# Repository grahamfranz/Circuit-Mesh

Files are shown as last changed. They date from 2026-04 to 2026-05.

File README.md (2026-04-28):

# circuit mesh

A parametric 3D-printable prototyping board for poke-through component mounting. Push component leads through the holes, twist or solder connections underneath — same workflow as the classic paper-over-cardboard method, but reusable and dimensionally consistent.

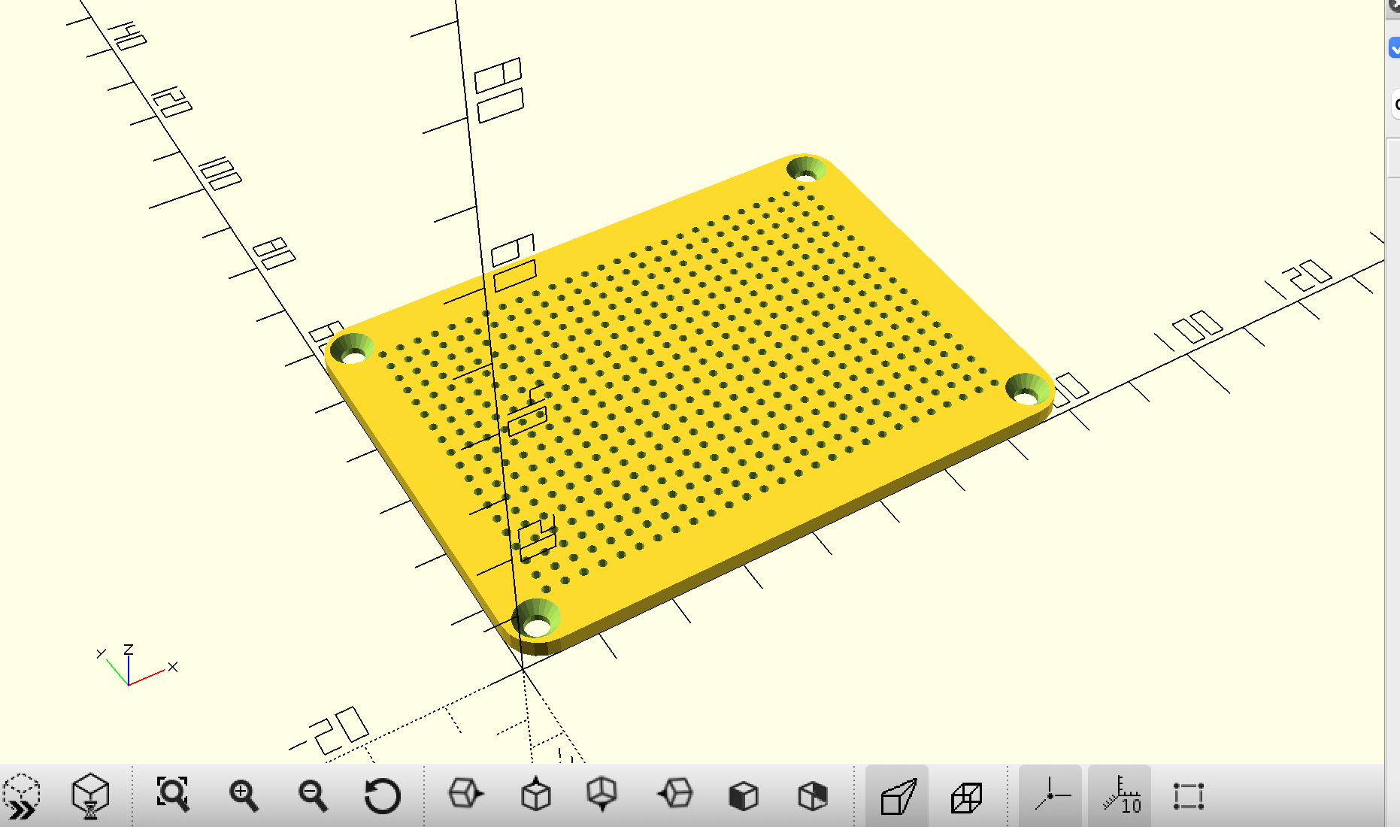
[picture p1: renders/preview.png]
circuit mesh render


---

## Hammond die-cast enclosure presets

Set the `preset` parameter to size the board footprint automatically for a standard Hammond die-cast enclosure. The board will fit inside the enclosure, accounting for wall thickness. The dimensions below are the *outer* enclosure footprints; `enclosure_wall_thick` (default 2.5mm per side) is automatically subtracted so your board fits with clearance.

| Preset | L (mm) | W (mm) | H (mm) | Notes |
|---|---|---|---|---|
| `1590A` |  92.5  |  38.5  |  31 | Micro, single-knob builds |
| `1590B` | 112 |  60 |  31 | Standard "Boss-style" pedal  |
| `1590BB`  | 119 |  94 |  34 | 3–4 knob builds |
| `125B` | 121 |  66 |  39 | Deeper 1590B alternative |
| `custom`  | — |  — |  — | Use `custom_board_width` / `custom_board_depth` |

`board_thick` (PCB thickness, default 2.5 mm) and `enclosure_wall_thick` (default 2.5 mm per side) are independent of the preset and should be adjusted separately based on your enclosure and material.

---

## print settings

- **Material:** TPU recommended for best grip. PETG works. PLA is functional but stiff.
- **Layer height:** 0.15–0.2mm
- **Infill:** 100% (it's thin — just do it)
- **Supports:** None needed
- **Orientation:** Flat on the bed, holes vertical
- **Nozzle/speed:** Small holes benefit from a 0.4mm nozzle and slow perimeter speed (20–25mm/s). Larger nozzles or fast speeds may produce irregular holes.

---

## parameters

Open `circuit_mesh.scad` in [OpenSCAD](https://openscad.org) and adjust the values at the top:

| Parameter | Default | Description |
|---|---|---|
| `preset` | `"custom"` | Hammond enclosure preset — see table above |
| `custom_board_width` | 80mm | Board width, used only when `preset = "custom"` |
| `custom_board_depth` | 60mm | Board depth, used only when `preset = "custom"` |
| `enclosure_wall_thick` | 2.5mm | Wall thickness of Hammond enclosure per side — subtracted automatically from preset dimensions |
| `board_thick` | 2.5mm | Thickness — more grip, harder insertion. Can be reduced to 2.0mm for lighter builds; consider 3mm if using screw holes |
| `hole_dia` | 1.2mm | Lead hole diameter — tune per material |
| `pitch` | 2.54mm | Hole spacing (standard component pitch) |
| `margin` | 5mm | Border around the hole grid |
| `corner_radius` | 5mm | Radius of rounded corners to fit Hammond enclosure corners |
| `add_screw_holes` | true | Corner M3 mounting holes with countersink — set to false to disable |
| `screw_margin` | 4mm | Distance from board corner to screw center |
| `countersink_dia` | 6.0mm | M3 flat head countersink diameter |
| `countersink_depth` | 1.5mm | Depth of countersink recess |

Hit **F6** to render, then **File → Export → STL**.

### hole diameter tuning

FDM printers tend to print holes slightly larger than specified. Hole size significantly affects insertion feel and component grip. The default (1.2mm) works well across materials. Suggested adjustments:

- TPU: 0.85mm (tighter tolerance for better grip)
- PETG: 1.2–2.0mm (larger holes allow easy component insertion; leads bend naturally)
- PLA: 1.0–1.2mm (smaller than PETG but still loose enough for easy insertion without forcing)

Resin printers may require tighter tolerances (closer to 0.85mm) due to higher accuracy.

---

## pre-rendered stls

Ready-to-print STL files for all Hammond enclosure presets are in the `renders/` folder:

| Filename | Preset | Grid | File size |
|---|---|---|---|
| `circuit_mesh_1590A.stl` | 1590A | 30 × 9 (270 holes) | 2.2M |
| `circuit_mesh_1590B.stl` | 1590B | 38 × 17 (646 holes) | 5.1M |
| `circuit_mesh_1590BB.stl` | 1590BB | 40 × 31 (1,240 holes) | 9.6M |
| `circuit_mesh_125B.stl` | 125B | 41 × 20 (820 holes) | 6.4M |
| `circuit_mesh_custom.stl` | custom | 27 × 19 (513 holes) | 4.1M |

Just download and print — no OpenSCAD needed. To customize, edit `circuit_mesh.scad`, render with **F6**, and export to STL via **File → Export**.

---

## use

- Push component leads through from the top
- Twist leads together underneath to connect, or solder for permanent joints
- Standard 2.54mm pitch means DIP ICs, resistors, capacitors, TO-92 transistors all fit naturally

---

## license

MIT

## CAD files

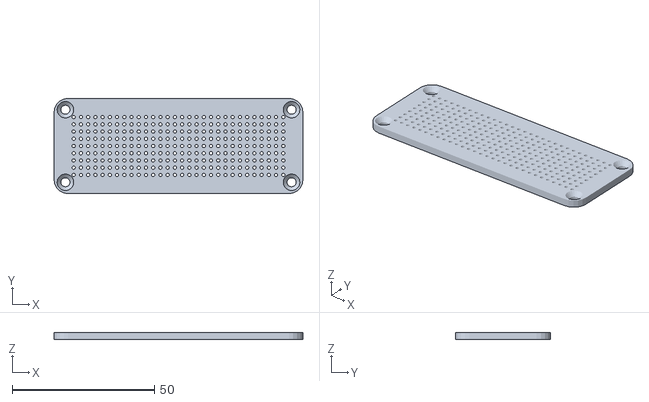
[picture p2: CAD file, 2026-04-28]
renders/circuit_mesh_1590A.stl
87.5 x 33.5 x 2.50

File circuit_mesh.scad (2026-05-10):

// ============================================
// Poke-Through Prototyping Board
// ============================================

// --- Hammond die-cast enclosure preset ---
// Options: "1590A"  (92.5 x 38.5 mm outer, 31 mm deep)
//          "1590B"  (112  x 60   mm outer, 31 mm deep)
//          "1590BB" (119  x 94   mm outer, 34 mm deep)
//          "125B"   (121  x 66   mm outer, 39 mm deep)
//          "barre_controller" – Barre-Controller enclosure mode (4 barres, default 37 mm pitch)
//                               Board: 106 x 133 mm. Keep screw_margin = 4 (default).
//                               Place board at (12, 12) mm from the lower-panel outer corner
//                               so the four M3 screws land on the corner standoffs.
//                               ~8 mm component clearance above the board inside the shell.
//          "custom" - enter your own dimensions in custom_board_width / custom_board_depth
preset = "custom"; // [1590A, 1590B, 1590BB, 125B, barre_controller, custom]

// Wall thickness of Hammond enclosure - subtract from outer dimensions to get inner space
// Typical die-cast boxes: 2.5mm per side = 5mm total reduction
enclosure_wall_thick = 2.5;  // mm - adjust if your enclosure has different wall thickness

// Board footprint - edit these only when preset = "custom":
custom_board_width = 80;  // mm
custom_board_depth = 60;  // mm

// Outer dimensions of Hammond boxes (from specifications)
outer_board_width = preset == "1590A"           ?  92.5 :
                    preset == "1590B"           ? 112   :
                    preset == "1590BB"          ? 119   :
                    preset == "125B"            ? 121   :
                    preset == "barre_controller"? 106   :
                    custom_board_width;

outer_board_depth = preset == "1590A"           ?  38.5 :
                    preset == "1590B"           ?  60   :
                    preset == "1590BB"          ?  94   :
                    preset == "125B"            ?  66   :
                    preset == "barre_controller"? 133   :
                    custom_board_depth;

// Subtract wall thickness on both sides (2x wall_thick) to get dimensions that fit inside.
// barre_controller uses direct board dimensions (no wall subtraction needed).
is_custom = (preset == "custom") || (preset == "barre_controller");
board_width = is_custom ? outer_board_width : (outer_board_width - 2*enclosure_wall_thick);
board_depth = is_custom ? outer_board_depth : (outer_board_depth - 2*enclosure_wall_thick);

// Enclosure interior height - informational reference, not used in board geometry.
// Tells you how much vertical clearance the chosen Hammond box provides.
enclosure_height = preset == "1590A"           ? 31 :
                   preset == "1590B"           ? 31 :
                   preset == "1590BB"          ? 34 :
                   preset == "125B"            ? 39 :
                   preset == "barre_controller"?  8 :  // mm above board inside shell
                   0;   // 0 = no preset selected

board_thick  = 2.5;   // mm - thicker = more grip, harder to insert (2.0mm for lighter builds)

hole_dia     = 1.2;   // mm - tuning per material and printer:
                      // TPU: 0.85mm | PETG: 1.2-2.0mm | PLA: 1.0-1.2mm
                      // Larger holes prevent tight insertion and allow easy lead bending
pitch        = 2.54;  // mm - standard component pitch, don't change unless needed

margin       = 5;     // mm - border around the hole grid

corner_radius = 5;    // mm - round the board corners to fit rounded Hammond enclosures

// --- Mounting screw holes ---
add_screw_holes    = true;
screw_dia          = 3.2;  // mm - M3 clearance
screw_margin       = 4;    // mm - distance from corner to screw center
countersink_dia    = 6.0;  // mm - M3 flat head countersink diameter
countersink_depth  = 1.5;  // mm - depth of countersink recess

// ============================================
// Derived values (don't edit)
cols = floor((board_width  - margin*2) / pitch);
rows = floor((board_depth - margin*2) / pitch);

// Center the grid on the board
x_offset = (board_width  - (cols - 1) * pitch) / 2;
y_offset = (board_depth - (rows - 1) * pitch) / 2;

// Corner screw positions
screw_positions = [
    [screw_margin,               screw_margin],
    [board_width - screw_margin, screw_margin],
    [screw_margin,               board_depth - screw_margin],
    [board_width - screw_margin, board_depth - screw_margin]
];

// ============================================
// Build it

difference() {
    // Base plate with rounded corners
    linear_extrude(board_thick) {
        offset(r=corner_radius, $fn=20) {
            translate([corner_radius, corner_radius])
                square([board_width - 2*corner_radius, board_depth - 2*corner_radius]);
        }
    }

    // Grid of holes
    for (x = [0 : cols-1]) {
        for (y = [0 : rows-1]) {
            translate([
                x_offset + x * pitch,
                y_offset + y * pitch,
                -0.1  // slight Z offset to ensure clean bottom cut
            ])
            cylinder(
                h = board_thick + 0.2,
                d = hole_dia,
                $fn = 12   // low poly cylinder - fine at this scale, faster preview
            );
        }
    }

    // Corner screw holes with countersink
    if (add_screw_holes) {
        for (pos = screw_positions) {
            // Clearance hole through full thickness
            translate([pos[0], pos[1], -0.1])
                cylinder(d=screw_dia, h=board_thick + 0.2, $fn=20);
            // Countersink recess on top
            translate([pos[0], pos[1], board_thick - countersink_depth])
                cylinder(d1=screw_dia, d2=countersink_dia, h=countersink_depth + 0.1, $fn=20);
        }
    }
}

// ============================================
// Print info to console
echo(str("Grid: ", cols, " x ", rows, " = ", cols*rows, " holes"));

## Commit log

2026-04-28 Initial commit: parametric circuit mesh board with Hammond enclosure integration
    [circuit_mesh.scad, circuit_mesh.stl]
2026-04-28 Add rendered STLs for all Hammond enclosure presets
    - 1590A (micro/single-knob): 270 holes
    - 1590B (standard Boss-style): 646 holes
    - 1590BB (3-4 knob): 1240 holes
    - 125B (deeper alternative): 820 holes
    - custom (default dimensions): 513 holes
    [circuit_mesh_1590A.stl]
2026-04-28 Update README with pre-rendered preset STLs table
    Replace generic example with detailed table of all 5 preset files,
    grid dimensions, and file sizes. Remove outdated default STL reference.
2026-05-10 Add barre_controller preset for Barre-Controller enclosure mode
    106 x 133 mm board sized to span the lower panel standoffs (98 x 125 mm
    standoff gap + 2x default 4 mm screw margin). Screw holes land exactly on
    the four M3 corner standoffs when the board is placed 12 mm inset from the
    outer panel corner. Fits inside the locating rim (124 x 151 mm interior)
    with clearance. ~8 mm component headroom above the board inside the shell.
    Grid: 37 x 48 = 1776 holes. Includes pre-rendered STL.
    [circuit_mesh.scad]
